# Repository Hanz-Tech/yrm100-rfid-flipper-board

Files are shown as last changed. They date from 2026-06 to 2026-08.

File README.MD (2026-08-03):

# YRM100 UHF RFID Flipper Zero Hat

A hat-style adapter PCB that plugs directly into the **Flipper Zero** and connects to the **YRM100/1/2/3 UHF RFID module**, enabling long-range RFID reading/writing out of the box.
Works with YRM1001/YRM1002/YRM1003 boards.

Available for purchase from [Tindie](https://www.tindie.com/products/hanztech/flipper-zero-uhf-rfid-yrm100x-adapter/) or [Etsy](https://www.etsy.com/ca/listing/4545558711/flipper-zero-uhf-rfid-yrm100x-adapter)

## Overview

This adapter board bridges the Flipper Zero's GPIO headers to the YRM100 UHF RFID module via a plug-and-play form factor. It provides:

- **5V power** and **3.3V logic** from the Flipper Zero
- **Crossed UART** (TX ↔ RX) for serial communication with the YRM100

- **Power switch** 

## Images

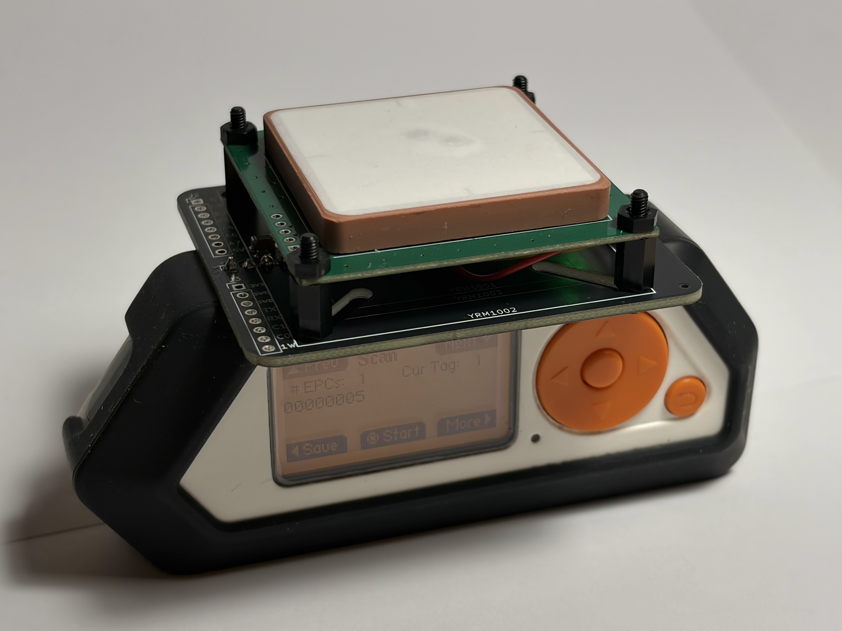
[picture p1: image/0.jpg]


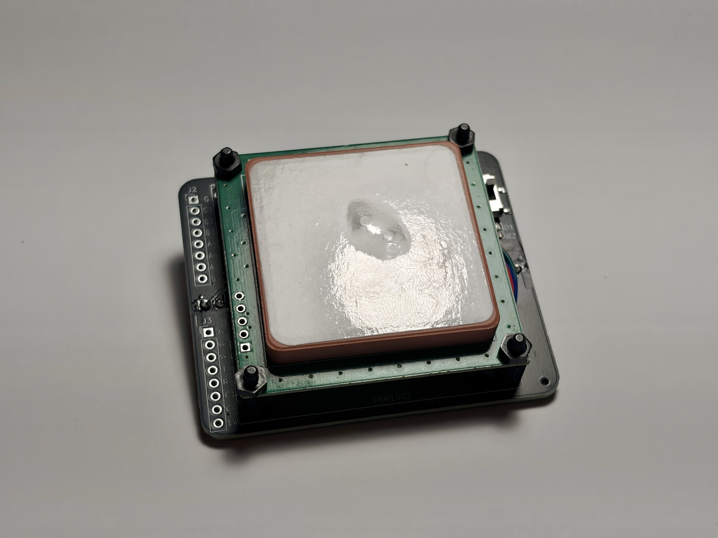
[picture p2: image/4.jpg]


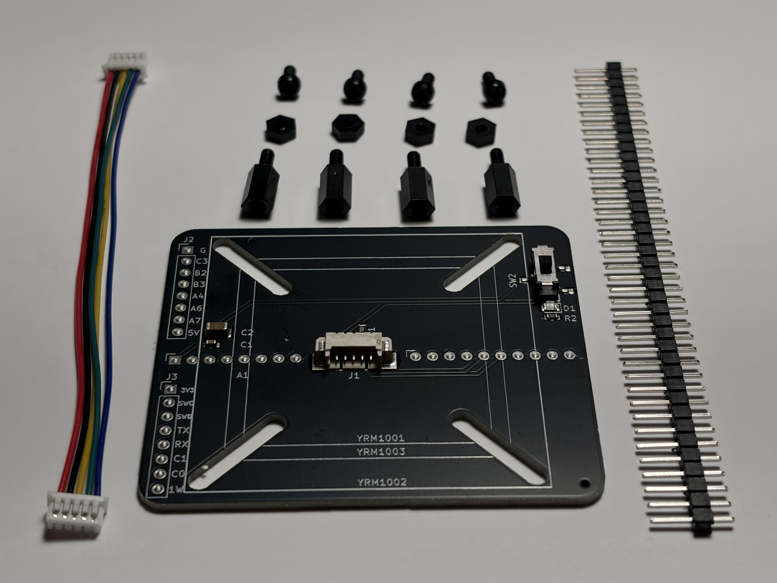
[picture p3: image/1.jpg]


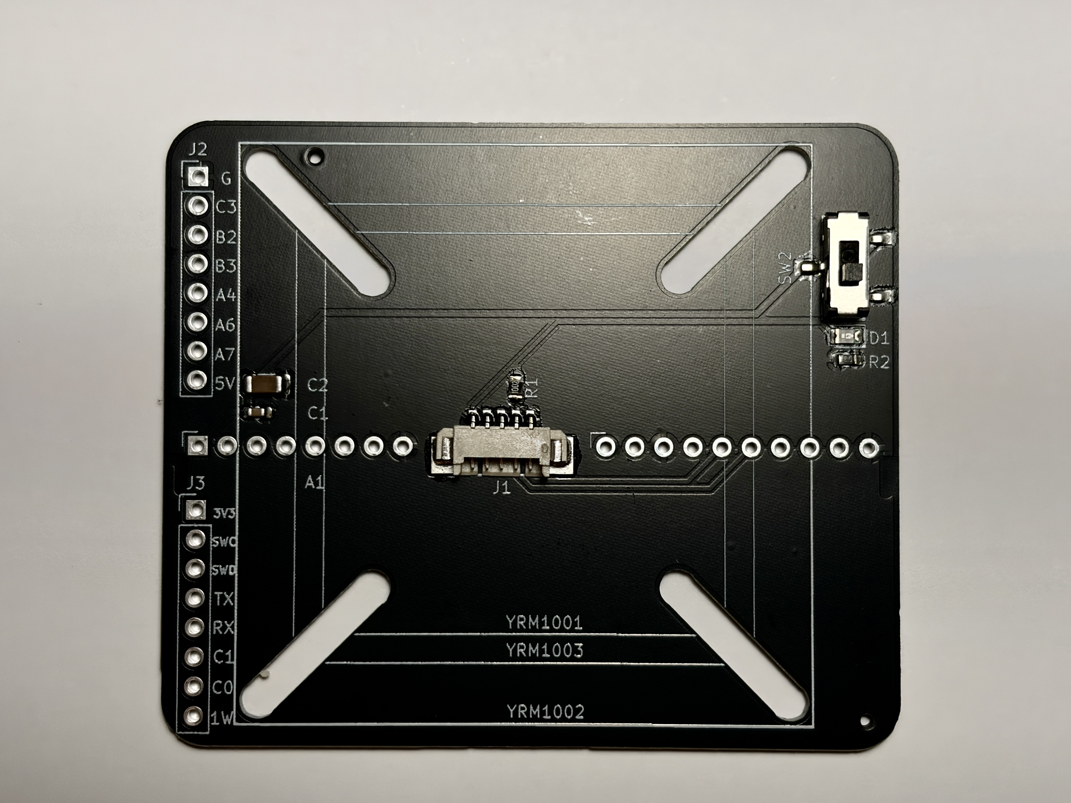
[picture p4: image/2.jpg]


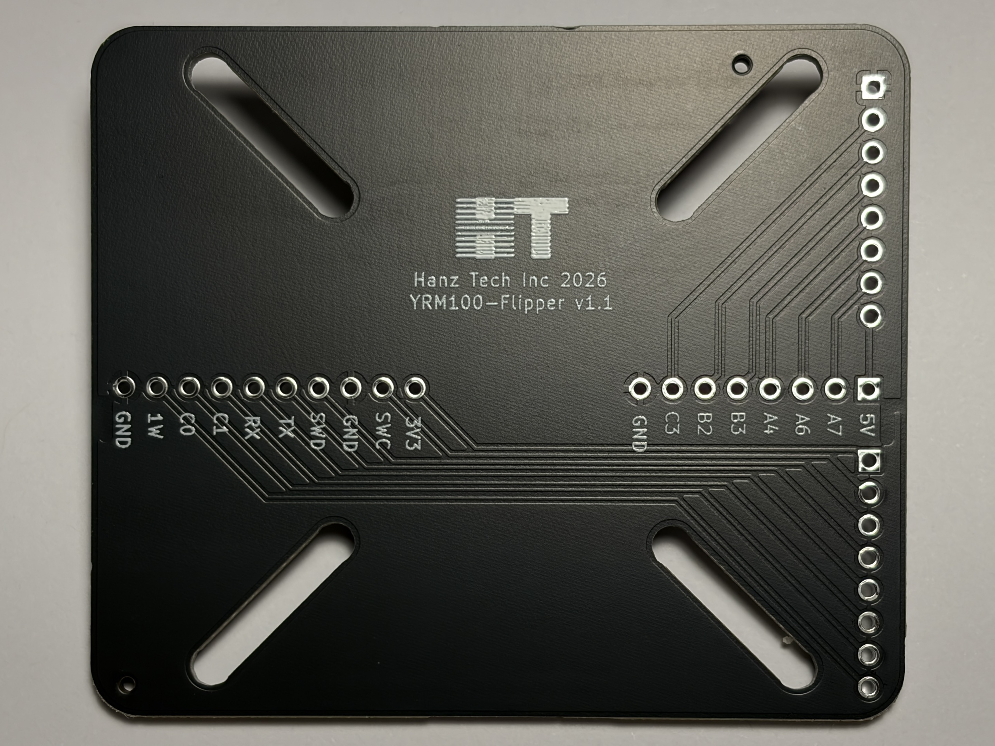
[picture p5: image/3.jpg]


## Connectors

### Flipper Zero (2× 1×8 headers, 2.54 mm pitch)

| Pin | Signal | Pin | Signal |
|-----|---|-----|---|
| 1 | **5V** | 9 | **3.3V** |
| 2 | PC0 (GPIO) | 10 | SWC |
| 3 | PC1 (GPIO) | 11 | GND |
| 4 | PC2 (GPIO) | 12 | SIO |
| 5 | PC3 (GPIO) | 13 | **TX** → YRM100 RX |
| 6 | PB3 (GPIO) | 14 | **RX** ← YRM100 TX |
| 7 | PB2 (GPIO) | 15 | C1 |
| 8 | **GND** | 16 | C0 |

> **Note:** UART is crossed — Flipper TX (Pin 13) connects to YRM100 RX, and Flipper RX (Pin 14) connects to YRM100 TX.

### YRM100 Module (5-pin JST 1.25 mm pitch)

| Pin | Signal |
|-----|---|
| 1 | 5V |
| 2 | GND |
| 3 | TX |
| 4 | RX |
| 5 | EN (pulled up to 3.3V via 10 kΩ) |

## Files

| File | Description |
|---|---|
| `yrm100_adapter.kicad_sch` | Schematic (KiCad 9.0) |
| `yrm100_adapter.kicad_pcb` | PCB layout (KiCad 9.0) |
| `yrm100_adapter.kicad_pro` | Project settings and design rules |

## Building / Ordering

1. Open `yrm100_adapter.kicad_pcb` in KiCad 9.0+
2. Run **Design Rules Check** (DRC) — should report zero violations
3. Run **Electrical Rules Check** (ERC) on the schematic — should report zero errors
4. Export **Gerber files** and **drill files** for PCB fabrication
5. Generate **BOM** and **position file** for component assembly

> **Note:** Verify exact footprints and component values against the schematic before ordering. Use the KiCad BOM generator for a complete parts list.

## License

MIT License

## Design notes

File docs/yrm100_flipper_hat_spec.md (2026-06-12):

# YRM100 to Flipper Zero Hat Adapter (Top-Mount)

## Goal

Build a compact adapter board inspired by the form factor shown in `white_3.JPG` — a low-profile, stacked arrangement featuring:

- **Thin adapter PCB** stacked directly on the Flipper Zero
- **Low-profile GPIO header** connecting the adapter to Flipper (minimal vertical spacing)
- **Short cable loop** from adapter to YRM100 module above
- **Minimal overall stack height** — components lay flat with little vertical buildup

## Electrical Mapping

Use 3.3V logic and cross UART TX/RX.

| YRM100 | Flipper Zero GPIO | Notes |
|---|---|---|
| VCC | +3.3V (pin 9) | Do not use 5V for UART logic |
| GND | GND (pin 8) | Common ground |
| TX | UART RX (PA6, pin 3) | Crossed UART |
| RX | UART TX (PA7, pin 2) | Crossed UART |
| EN (if present) | Pull-up to 3.3V via 10k or optional GPIO | Keep enabled by default |

## Connectors

### 1. Flipper side (bottom)
- 1x9 male 2.54 mm pin header, straight, through-hole
- Pins point downward into Flipper GPIO socket

### 2. YRM100 side (top)
- **Primary**: 1x4 JST-PH 2.0 mm vertical through-hole (RX, TX, VCC, GND)
- **Optional fallback footprint in parallel**: 1x5 2.54 mm header (VCC, TXD, RXD, EN, GND)

> **Reason for dual option**: YRM100 variants in the field use either a 4-wire JST cable or a 5-pin breakout harness.

## Board Outline (recommended)

- Board size: 52 mm x 28 mm
- Corner radius: 2 mm
- 2-layer PCB, 1.6 mm FR4

This size is still compact but gives room for mounting slots and strain relief.

## Universal Top-Mount Mechanical Pattern

Because YRM100 board sizes differ by seller, use slots (not fixed holes):

### Left slot rail
- Slot A center: (8.0, 8.0) mm
- Slot B center: (8.0, 20.0) mm
- Slot size: 8.0 mm x 3.2 mm (for M2/M2.5 hardware)

### Right slot rail
- Slot C center: (44.0, 8.0) mm
- Slot D center: (44.0, 20.0) mm
- Slot size: 8.0 mm x 3.2 mm

Coordinate origin: lower-left board corner at (0,0).

This gives adjustable mounting width and lets you clamp different YRM100 board hole spacings.

## Placement Targets

### 1. Flipper 1x9 header
- Place along X = 26.0 mm centerline
- First pin center at (26.0, 3.5) mm
- Pin pitch 2.54 mm upward in +Y

### 2. YRM100 JST connector
- Place near top edge for short cable loop
- Suggested center: (26.0, 24.0) mm
- Key notch facing outward (toward top edge)

### 3. Optional 5-pin fallback header
- Place parallel and 6.0 mm behind JST
- Suggested center: (26.0, 17.5) mm

## Power Integrity

Place near YRM100 power entry:
- C1: 100 nF ceramic between 3.3V and GND
- C2: 22 µF bulk capacitor between 3.3V and GND
- Keep both within 8 mm of YRM100 power pins

## Routing Rules

- **Trace width**:
  - Power: 0.50 mm
  - UART/data: 0.25 mm
- **Clearance**: 0.20 mm minimum
- Keep UART traces short and avoid crossing under slot areas
- Add GND copper pour on both layers

## Silkscreen

Add clear labels on top side:
- YRM100: RX TX 3V3 GND EN
- Flipper side arrow: PIN 1 and PIN 9
- Warning text: "3.3V UART ONLY"

## Assembly Stack (low height)

1. Bottom: short male GPIO pins to Flipper
2. Mid: adapter PCB
3. Top: JST connector and YRM100 board
4. Hardware: M2 nylon standoffs, 4-6 mm length

## Validation Checklist

### 1. Continuity
- YRM100 TX to Flipper PA6
- YRM100 RX to Flipper PA7
- 3.3V and GND correct

### 2. No shorts
- 3.3V to GND resistance check before power-on

### 3. Fit check
- Board inserts fully into Flipper GPIO
- No collision with Flipper shell
- YRM100 can be bolted using slot rails

## Important Note

Large AliExpress dimension variants are often antenna size options, not always the controller PCB footprint. Using slot rails plus a cable entry connector is the most reliable way to support variant boards without redesigning the adapter each time.

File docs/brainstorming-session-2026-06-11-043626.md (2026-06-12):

---
stepsCompleted: [1]
sessionTopic: YRM100 UHF RFID Flipper Zero Hat PCB
user: Han
project: rfid-flipper
date: 2026-06-11
language: English
---

# Brainstorming Session: YRM100 UHF RFID Flipper Zero Hat PCB

## Session Context

**Facilitator:** BMad Brainstorming Agent  
**User:** Han  
**Project:** rfid-flipper  
**Date:** 2026-06-11  
**Language:** English

---

## Session Topic

**YRM100 UHF RFID Hat PCB for Flipper Zero**

A hat-style PCB that interfaces between a YRM100 UHF RFID module board and a Flipper Zero, providing mechanical mounting (M2-M3 screws) and GPIO connectivity.

---

## Session Objectives

- Validate and refine the existing UART pass-through design
- Explore GPIO breakout features for YRM100 flexibility
- Optimize design for small-batch production (DFM, cost, assembly)
- Achieve plug-and-play user experience

---

## Design Constraints (Confirmed)

- **Core function**: UART pass-through (RX/TX cross, 3.3V, GND)
- **Additional feature**: GPIO breakout pins for YRM100
- **Production target**: Small batch (10–100 units)
- **User experience**: Plug-and-play — no drivers, no switches, no configuration
- **Power gating**: Explicitly excluded — direct connection, YRM100 runs whenever Flipper is on

---

## Decisions Made So Far

### Power
- **Bulk capacitance**: 47 µF / 6.3 V (0805) — transient current supply for YRM100 transmit spikes
- **Decoupling**: 100 nF / 6.3 V (0402) — high-frequency bypass near YRM100 power entry
- **Reverse protection**: BAT54 Schottky diode — prevents backfeed when hat is plugged in with Flipper off
- **UART idle pull-downs**: 2× 10 kΩ on RX/TX lines — clean idle state when YRM100 disconnected
- **Power OK LED**: Green LED + 100 Ω current limiter — visual confirmation hat is powered
- **Current sense test points**: 0.1 Ω sense points on VCC rail for debugging
- **Power gating**: ❌ Excluded — direct connection, no MOSFET switch

### GPIO Breakout — Hybrid Approach (Approach C)
- **YRM100 module pinout**: `5V | GND | TX | RX | EN` (5-pin)
- **YRM100 connector**: 5-pin **JST 1.0 mm pitch**
- **Flipper Zero GPIO**: Two separate 1×8 headers (16 pins total), 2.54 mm pitch
- **Hat connector to Flipper**: Two 1×8 headers, 2.54 mm pitch, ~18 mm row spacing
- **KiCAD library**: Correct header parts already available in the project library
- **Unused pins**: Pin 17 (1-Wire) and Pin 18 (GND) — unused

### Flipper Zero GPIO Pinout (from flipper_pin_out.md)

**LEFT SIDE (Pins 1–8)** — Hat row 1:
| Pin | Signal | Hat Usage |
|-----|---|---|
| 1 | 5V | YRM100 5V |
| 2 | PC0 | Breakout |
| 3 | PC1 | Breakout |
| 4 | PC2 | Breakout |
| 5 | PC3 | Breakout |
| 6 | PB3 | Breakout |
| 7 | PB2 | Breakout |
| 8 | GND | YRM100 GND |

**RIGHT SIDE (Pins 9–18)** — Hat row 2:
| Pin | Signal | Hat Usage |
|-----|---|---|
| 9 | 3.3V | UART logic / EN pull-up |
| 10 | SWD | Breakout |
| 11 | GND | YRM100 GND (common) |
| 12 | SIO | Breakout |
| 13 | TX | → YRM100 RX (crossed) |
| 14 | RX | → YRM100 TX (crossed) |
| 15 | C1 | Breakout |
| 16 | C0 | Breakout |
| 17 | 1 Wire | — (unused) |
| 18 | GND | — (unused) |

### Signal Routing Summary
- **YRM100 5V** ← Flipper Pin 1 (5V)
- **YRM100 GND** ← Flipper Pin 8 / 11 (common ground)
- **YRM100 TX** ← Flipper Pin 14 (RX) — crossed
- **YRM100 RX** ← Flipper Pin 13 (TX) — crossed
- **YRM100 EN** ← pulled up to 3.3V via 10 kΩ (on-board)
- **Breakout pins**: PC0, PC1, PC2, PC3, PB3, PB2 (left) + SWD, SIO, C1, C0 (right) = 10 signals

### Power Architecture (Updated)
- **YRM100 5V supply**: From Flipper GPIO Pin 1 (5V)
- **UART logic**: 3.3V from Flipper GPIO Pin 9 (3.3V)
- **Bulk capacitance**: 47 µF / 6.3 V (0805) — transient current supply for YRM100 transmit spikes
- **Decoupling**: 100 nF / 6.3 V (0402) — high-frequency bypass near YRM100 power entry
- **Reverse protection**: BAT54 Schottky diode on 5V rail — prevents backfeed when hat is plugged in with Flipper off
- **UART idle pull-downs**: 2× 10 kΩ on RX/TX lines — clean idle state when YRM100 disconnected
- **Power OK LED**: Green LED + 100 Ω current limiter — visual confirmation hat is powered
- **Current sense test points**: 0.1 Ω sense points on VCC rail for debugging
- **Power gating**: ❌ Excluded — direct connection, no MOSFET switch

---

## Ideas

_No ideas generated yet._

---

*Session in progress. Next step: Small-Batch Production Optimization*

---

## Decisions Made So Far

### Manufacturing
- **Panelization**: ❌ Not panelized — individual boards only
- **Manufacturing route**: JLCPCB/PCBWay assembly (assumed)
- **Surface finish**: HASL leaded (cheapest, hand-solder friendly)
- **Silkscreen**: White on green
- **PCB layers**: 2-layer, 1.6 mm FR4
- **Board size**: 52 × 28 mm (individual, no panel)

### DFM Rules
- **Power traces (5V, GND)**: 0.5 mm (20 mil) minimum
- **Signal traces (UART)**: 0.25 mm (10 mil) minimum
- **Clearance**: 0.2 mm (8 mil)
- **Via size**: 0.3 mm hole / 0.6 mm pad
- **Test points**: 5 exposed pads (5V, 3.3V, TX, RX, GND)

---

## Session Status

**Brainstorming complete.** Moving to KiCAD implementation phase.

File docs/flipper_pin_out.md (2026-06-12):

========================================
FLIPPER ZERO GPIO PINOUT REFERENCE
========================================

Pinout is viewed from the FRONT (screen facing you), starting from the top.

LEFT SIDE (Pins 1-8)
----------------------------------------
Pin 1 : 5V 
Pin 2 : PC0  GPIO 
Pin 3 : PC1  GPIO 
Pin 4 : PC2  GPIO
Pin 5 : PC3  GPIO 
Pin 6 : PB3  GPIO 
Pin 7 : PB2  GPIO 
Pin 8 : GND  (Ground)

RIGHT SIDE (Pins 9-18)
----------------------------------------
Pin 9 : 3.3V   
Pin 10 : SWC
Pin 11 : GND
Pin 12 : SIO
Pin 13 : TX
Pin 14 : RX
Pin 15 : C1
Pin 16 : C0
Pin 17 : 1 Wire
Pin 18 : GND  (Ground)
========================================
NOTES
========================================
- I/O pins are +3.3V tolerant.
- Do NOT connect 5V to the I/O pins.
- UART Bridge (USB-UART):
  TX -> Pin 15
  RX -> Pin 14

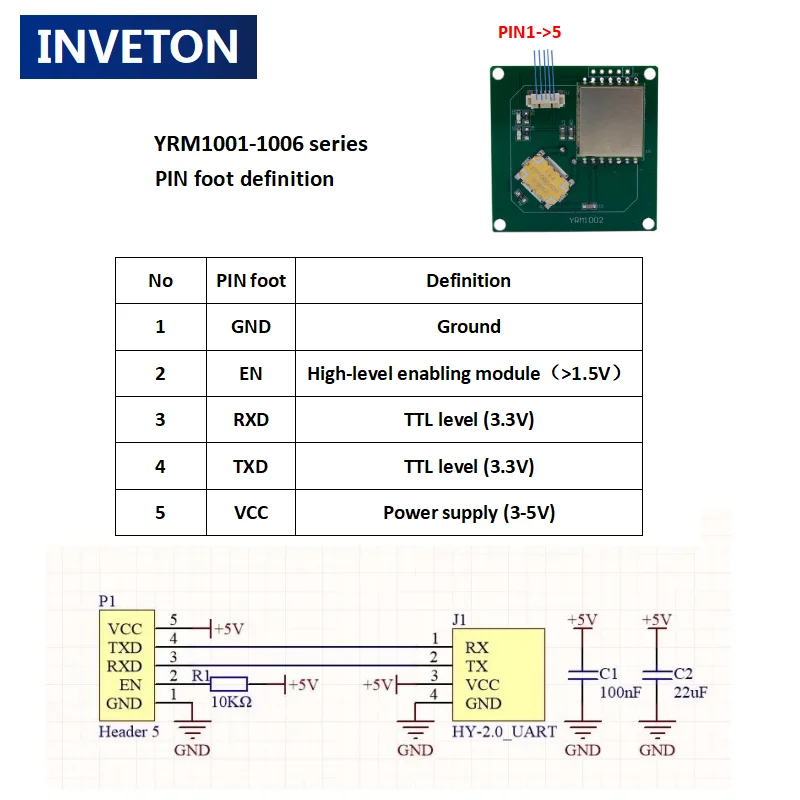
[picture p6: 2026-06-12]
docs/uart.webp

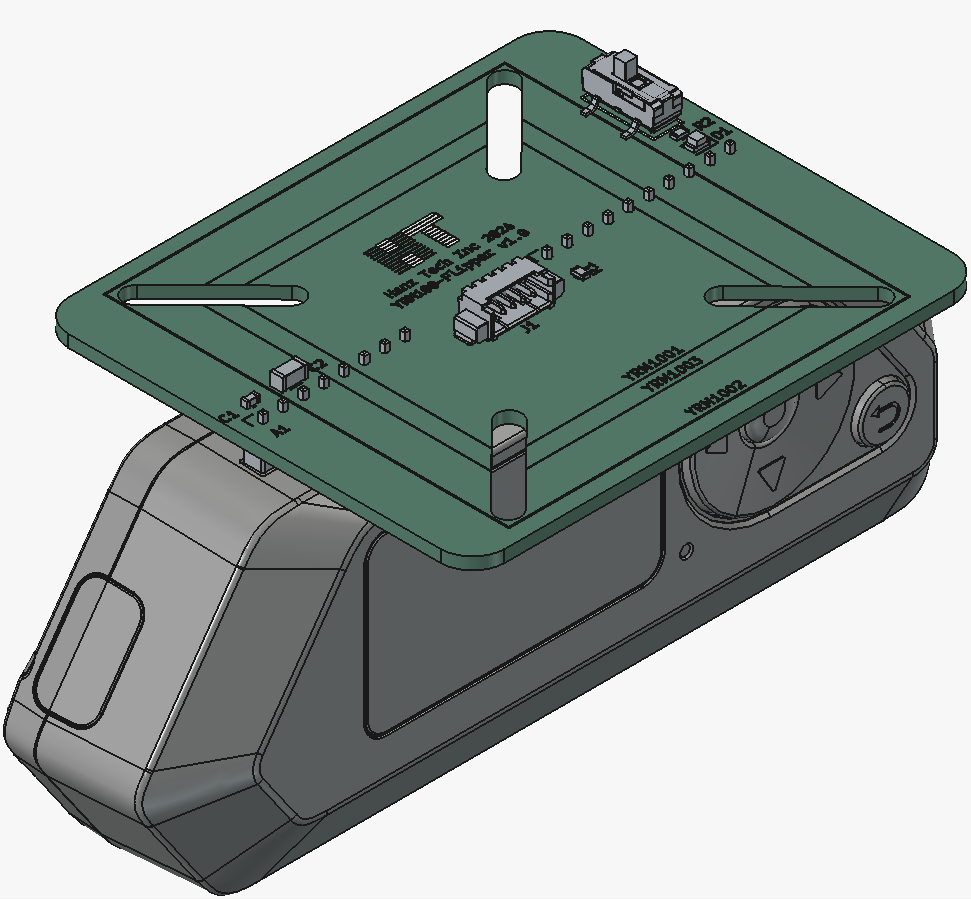
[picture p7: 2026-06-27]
image/with_flipper.png

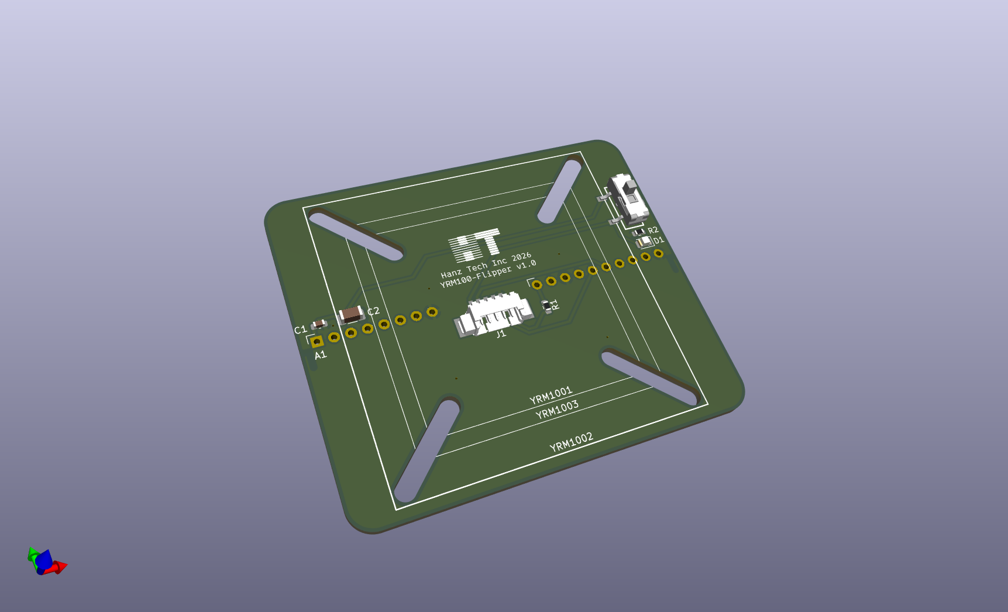
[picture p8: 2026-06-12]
yrm100_adapter.png

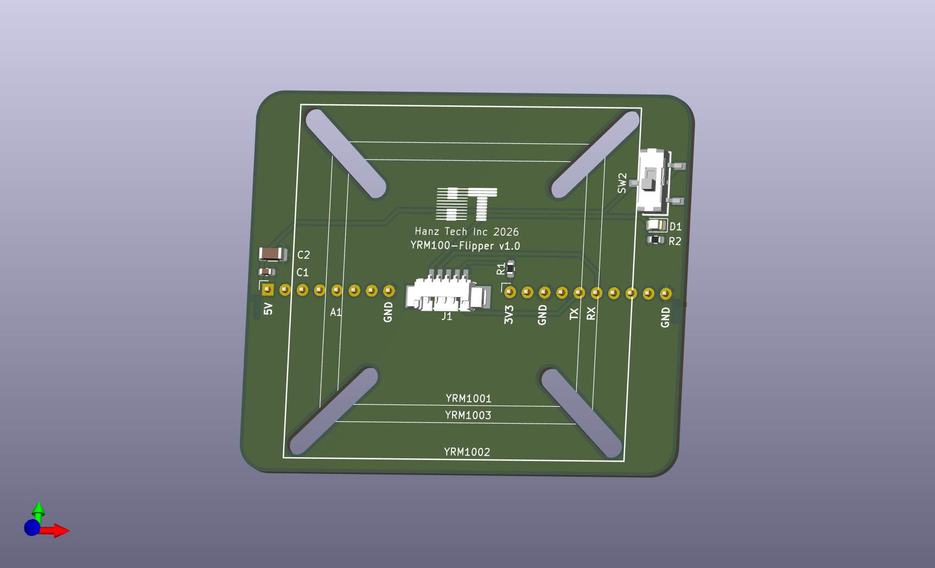
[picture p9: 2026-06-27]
image/yrm100_adapter_pcb.png

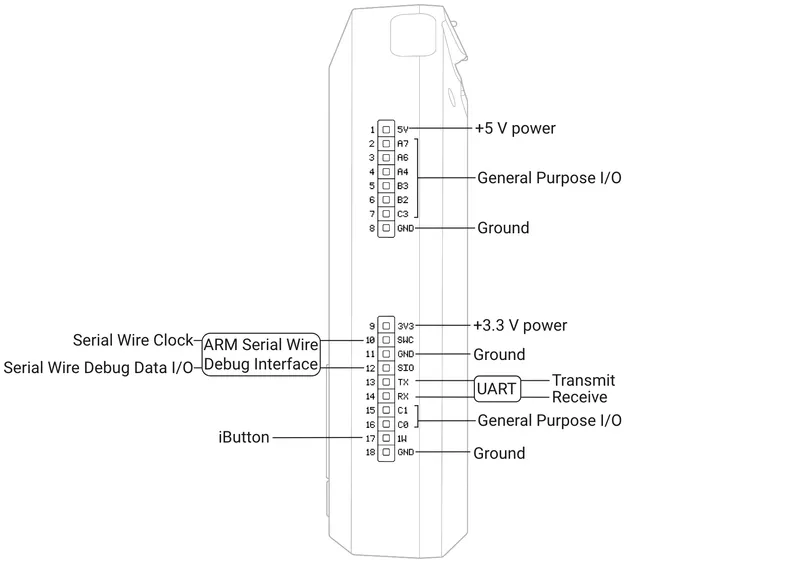
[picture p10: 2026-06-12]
docs/rDj495vJHGg8Ae5H_4vdo_image.webp

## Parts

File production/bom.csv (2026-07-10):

Designator | Footprint | Quantity | Value | LCSC Part #
C1 | 0603 | 1 | 100nF | C14663
C2 | 1206 | 1 | 22uF | C12891
D1 | 0805 | 1 | LED | C2297
J1 | CONN-SMD_5P-P1.25_1.25T-5PWT | 1 | Conn_01x05_Pin | C22076
R1 | 0603 | 1 | 10k | C17414
R2 | 0603 | 1 | 1K | C21190
SW2 | SW-SMD_K3-1235S-K1 | 1 | SW_Nidec_CAS-120A1 | C92660

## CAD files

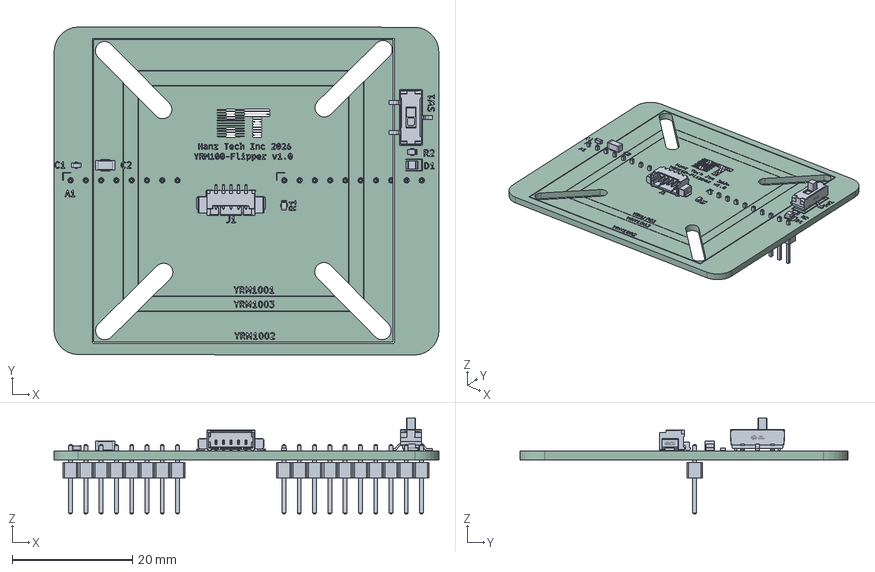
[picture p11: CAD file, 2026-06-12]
3dcad/yrm100_adapter.step
64.0 x 54.5 x 15.9 mm
CONN-SMD_MX1.25-WS-5P
C_0603_1608Metric
C_1206_3216Metric
SW-SMD_K3-1235S-K1
R_0603_1608Metric x 2
PinHeader_1x08_P2.54mm_Vertical
PinHeader_1x10_P2.54mm_Vertical
LED_0805_2012Metric
yrm100_adapter_silkscreen
yrm100_adapter_PCB

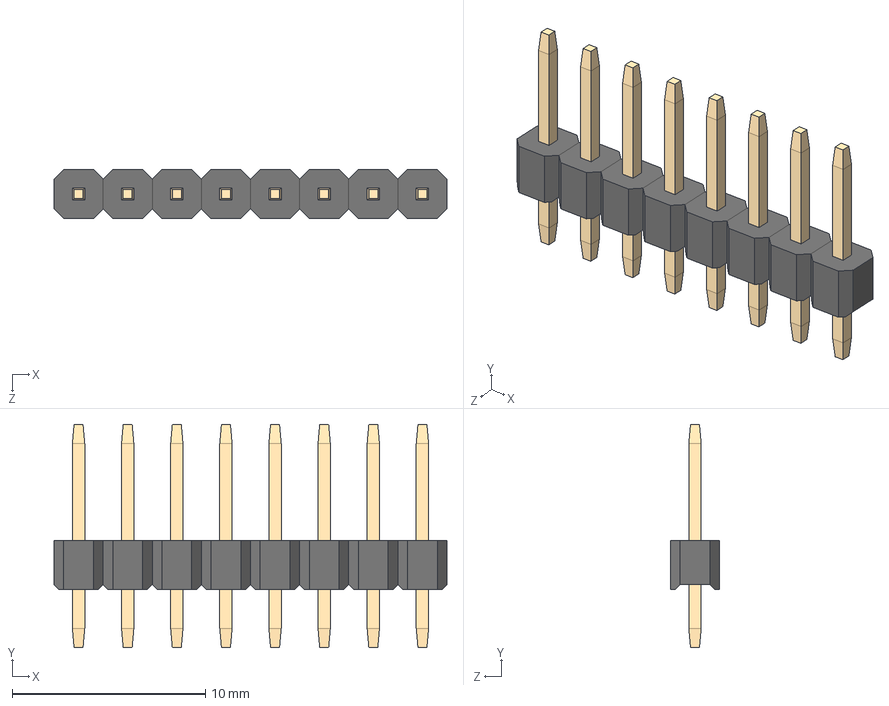
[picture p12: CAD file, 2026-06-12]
EASYEDA_MODELS/Header, Male, 2.54mm, 1x8.STEP
20.3 x 11.5 x 2.54 mm

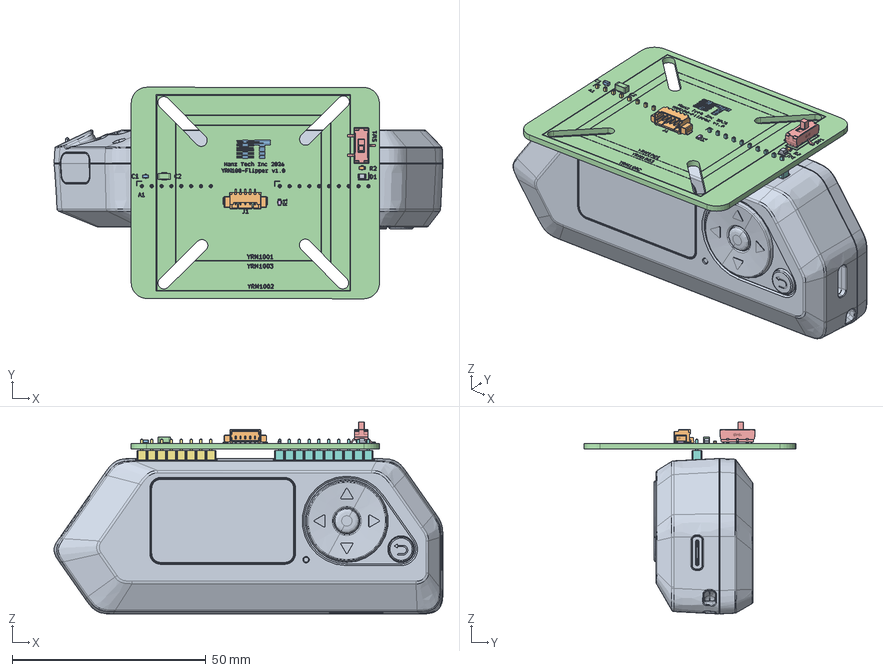
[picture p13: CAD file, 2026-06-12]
3dcad/yrm100-flipper.FCStd
100.3 x 54.5 x 49.5 mm
flipper-zero-body-3d
CONN-SMD_MX1.25-WS-5P
C_0603_1608Metric
C_1206_3216Metric
SW-SMD_K3-1235S-K1
R_0603_1608Metric
PinHeader_1x08_P2.54mm_Vertical
PinHeader_1x10_P2.54mm_Vertical
LED_0805_2012Metric
R_0603_1608Metric001
yrm100_adapter_silkscreen
yrm100_adapter_PCB

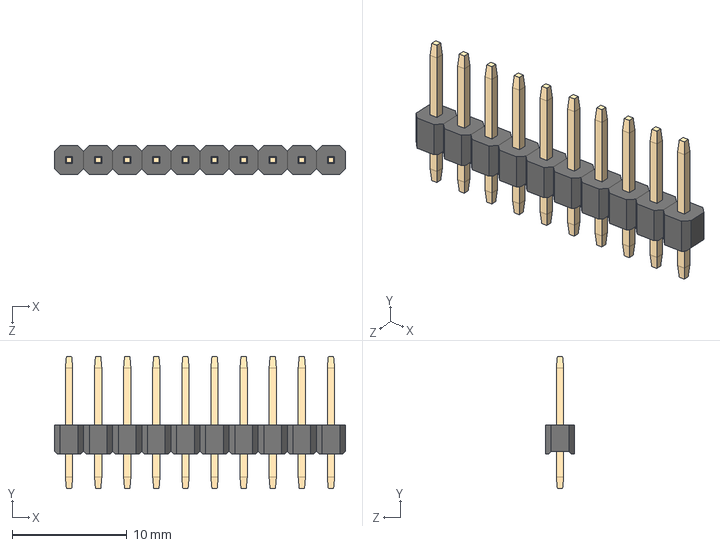
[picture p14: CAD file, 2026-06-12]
EASYEDA_MODELS/Header, Male, 2.54mm, 1x10.STEP
25.4 x 11.5 x 2.54 mm

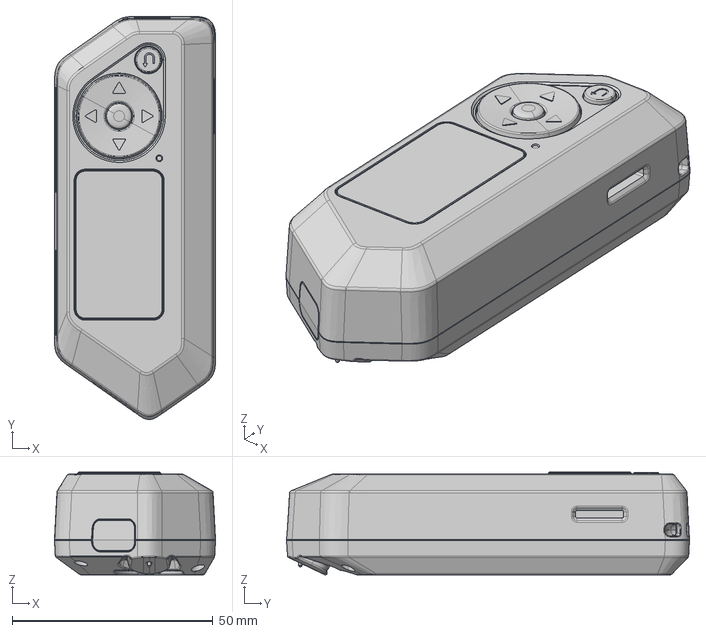
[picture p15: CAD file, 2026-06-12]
3dcad/flipper-zero-body-3d.stp
40.1 x 100.3 x 25.6 mm

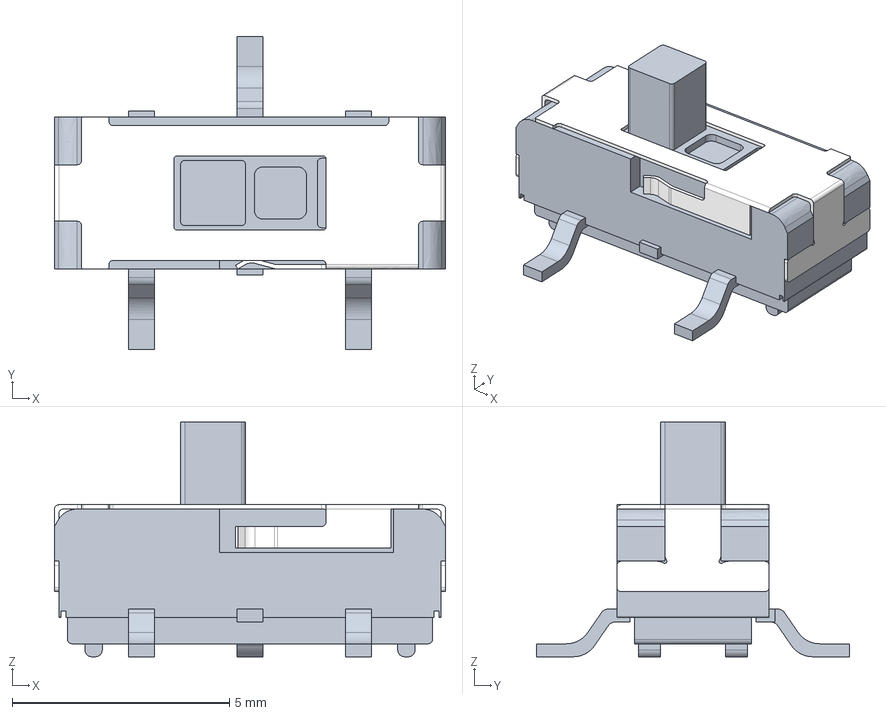
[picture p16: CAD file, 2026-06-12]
EASYEDA_MODELS/SW-SMD_K3-1235S-K1.step
9.00 x 7.20 x 5.40 mm

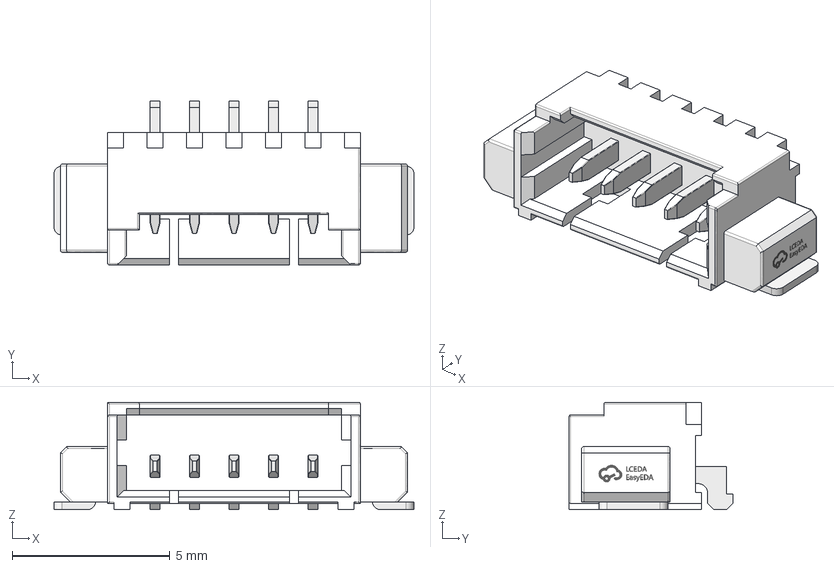
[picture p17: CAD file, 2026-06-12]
EASYEDA_MODELS/CONN-SMD_MX1.25-WS-5P.step
11.4 x 5.19 x 3.40 mm

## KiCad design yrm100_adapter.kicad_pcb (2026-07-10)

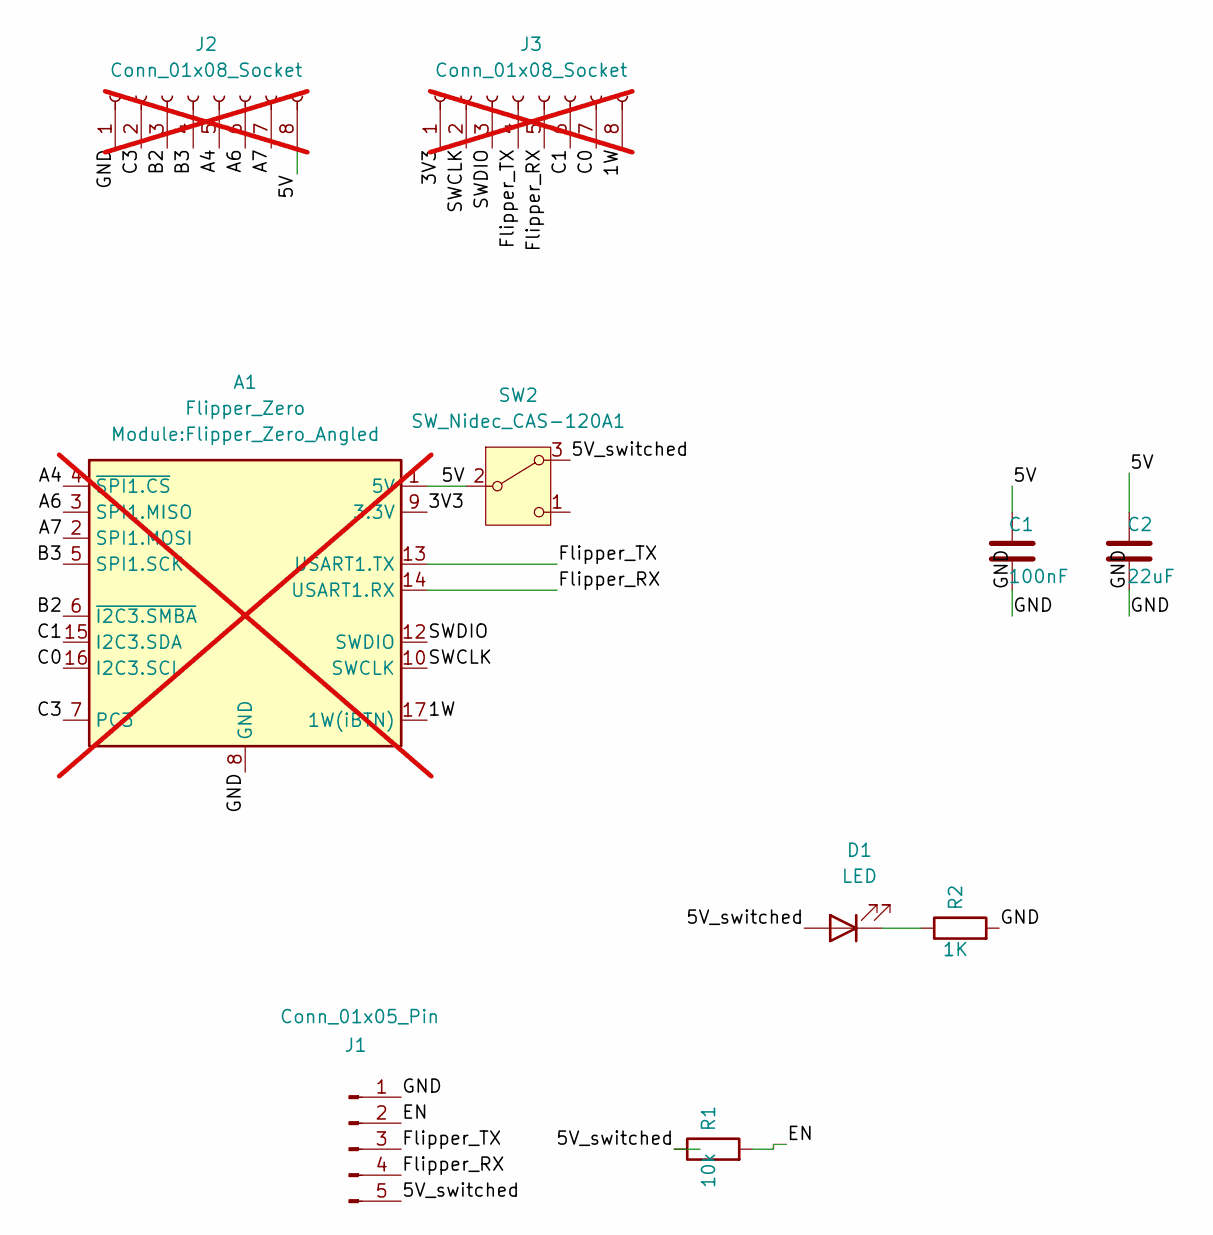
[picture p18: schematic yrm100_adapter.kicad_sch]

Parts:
A1: Flipper_Zero; Flipper_Zero_Angled; not fitted
C1: 100nF; C_0603_1608Metric; MPN CC0603KRX7R9BB104; LCSC C14663
C2: 22uF; C_1206_3216Metric; MPN CL31A226KAHNNNE; LCSC C12891
D1: LED; LED_0805_2012Metric; MPN KT-0805G; LCSC C2297
J1: Conn_01x05_Pin; CONN-SMD_5P-P1.25_1.25T-5PWT; MPN 1.25T-5P; LCSC C22076
J2, J3: Conn_01x08_Socket; PinHeader_1x08_P2.54mm_Vertical; not fitted
R1: 10k; R_0603_1608Metric; MPN 0805W8F1002T5E; LCSC C17414
R2: 1K; R_0603_1608Metric; MPN 0603WAF1001T5E; LCSC C21190
SW2: SW_Nidec_CAS-120A1; SW-SMD_K3-1235S-K1; LCSC C92660

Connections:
/1W: A1.17 (1W(iBTN)), J3.8
/3V3: A1.9 (3.3V), J3.1
/5V: A1.1 (5V), C1.1, C2.1, J2.8, SW2.2 (B)
/5V_switched: D1.2 (A), J1.5, R1.1, SW2.3 (A)
/A4: A1.4 (~SPI1.CS), J2.5
/A6: A1.3 (SPI1.MISO), J2.6
/A7: A1.2 (SPI1.MOSI), J2.7
/B2: A1.6 (~I2C3.SMBA), J2.3
/B3: A1.5 (SPI1.SCK), J2.4
/C0: A1.16 (I2C3.SCL), J3.7
/C1: A1.15 (I2C3.SDA), J3.6
/C3: A1.7 (PC3), J2.2
/EN: J1.2, R1.2
/Flipper_RX: A1.14 (USART1.RX), J1.4, J3.5
/Flipper_TX: A1.13 (USART1.TX), J1.3, J3.4
/GND: A1.8 (GND), A1.11 (GND), A1.18 (GND), C1.2, C2.2, J1.1, J2.1, R2.2
/SWCLK: A1.10 (SWCLK), J3.2
/SWDIO: A1.12 (SWDIO), J3.3
unnamed: D1.1 (K), R2.1

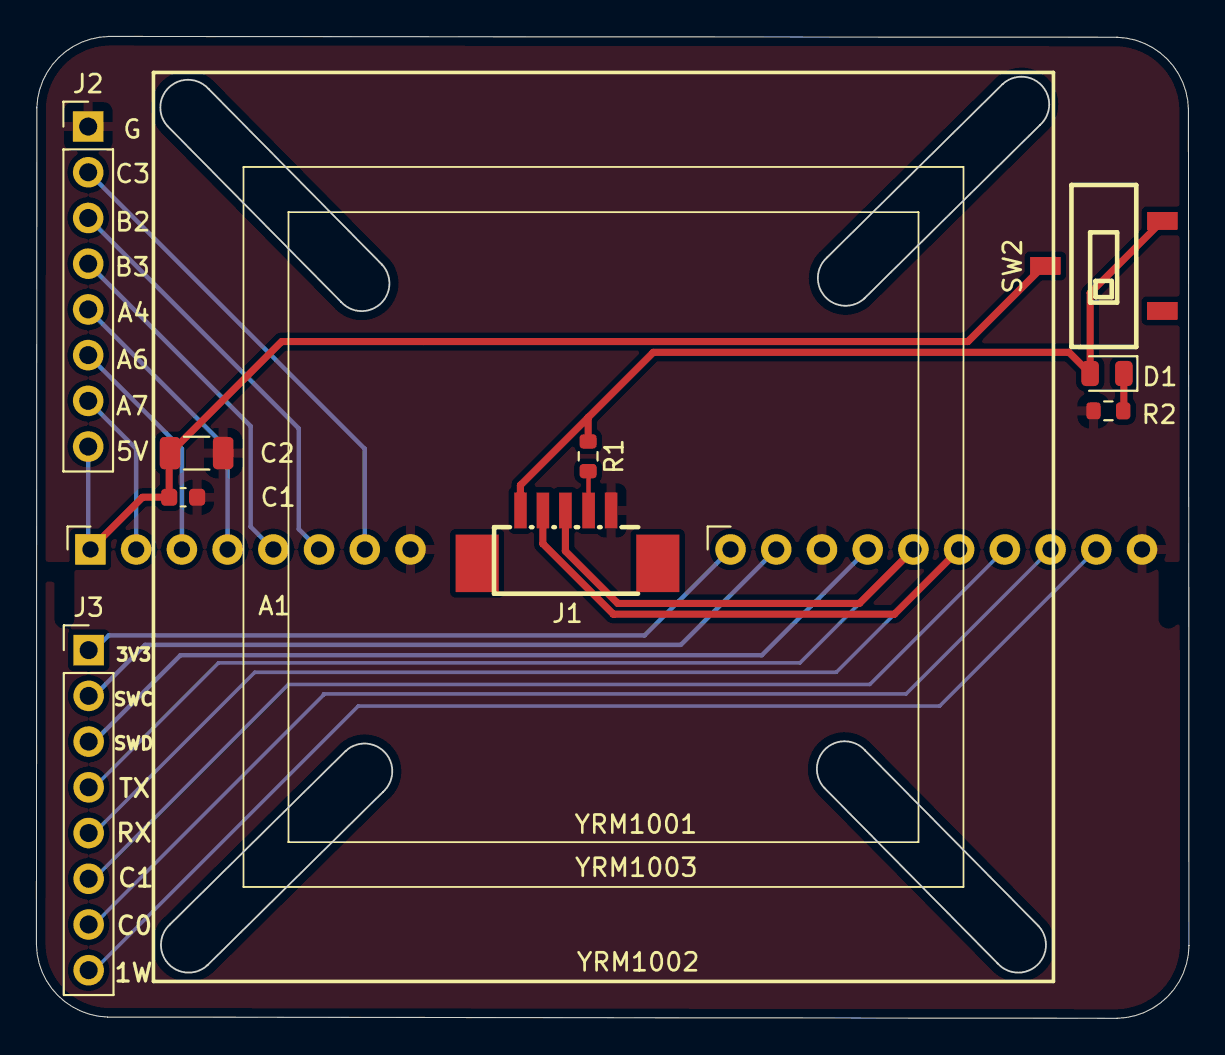
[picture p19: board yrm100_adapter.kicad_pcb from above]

Board: 2 copper layers, 64.0 x 54.5 mm, 10 parts (0 on the bottom side), 19 nets.

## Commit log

2026-06-12 add 3d cad model
    [flipper-zero-body-3d.stp, yrm100-flipper.FCStd, yrm100_adapter.kicad_sch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]
2026-06-13 move position of headers
    [bom.csv, positions.csv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]
2026-06-27 Update with images
    [bom.csv, designators.csv, positions.csv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]
2026-07-10 Changed LED resistor to 500ohm, added breakout header for GPIO
    [bom.csv, designators.csv, positions.csv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]
